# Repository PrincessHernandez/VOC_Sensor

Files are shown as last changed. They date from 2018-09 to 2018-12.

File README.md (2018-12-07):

# Build Instructions for Raspberry Pi VOC Sensor

## Table of Contents
1. [Introduction](#introduction)
2. [Material Requirements](#material-requirements)
3. [Raspberry Pi Configuration](#raspberry-pi-configuration)
4. [Mechanical Assembly and Soldering](#mechanical-assembly-and-soldering)
5. [I2C Detection](#i2c-detection)
6. [Power Up](#power-up)
7. [Explore with your Sensor](#explore-with-your-sensor)

### Introduction
Volatile Organic Compounds (VOC) can be found in everyday products such as cleaning supplies, paint, cosmetic products, fuel, and many more. They have the potential to contaminate our health, so monitoring air quality is very crucial for our everyday means. The CCS811 Air Quality Sensor can sense VOC and CO2, two parameters that are important for monitoring air quality. The following instructions are provided to assist you in developing a VOC sensor that can measure TVOC and eCO2 levels in the air.
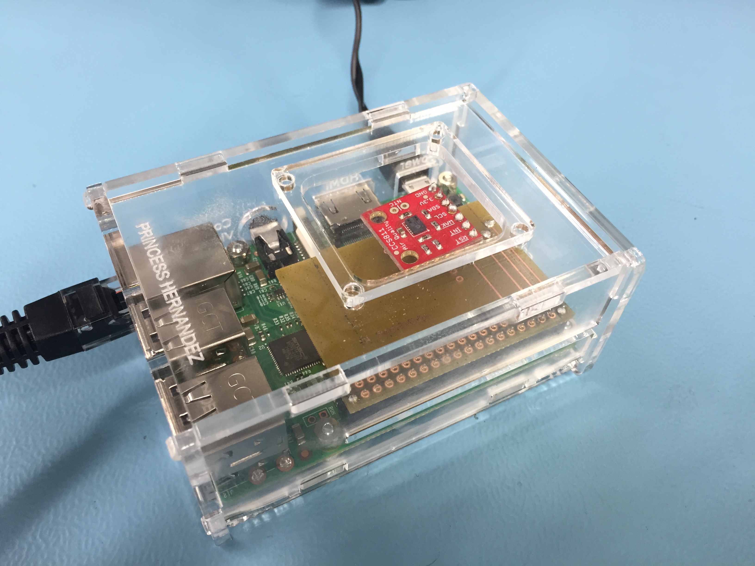
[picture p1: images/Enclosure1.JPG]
<br/></p>

> I recommend that before attempting this build that you have accomplished watching videos on [soldering](https://www.youtube.com/watch?v=BLfXXRfRIzY&list=PLQ32vZrF5U2lFOJTtZDytBWBYVLNp4RYz). 

### Material Requirements
The project's total budget will cost you approx. CAD$232.12 excluding tax and shipping. The prices can be converted depending on where you are from. If you would like to see my personal budget click [here](https://github.com/PrincessHernandez/VOC_Sensor/blob/master/documentation/BudgetUpdated.xlsx). Keep in mind that my budget costs lower because I own some of the parts (or had access to in Prototype Lab) from the list.
The following links below are sources of where you can purchase the items:
* [Raspberry Pi 3 Kit](https://www.amazon.ca/CanaKit-Raspberry-Complete-Starter-Kit/dp/B01CCF6V3A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) - CAD$99.99
* [CCS811 Air Quality Sensor](https://www.sparkfun.com/products/14193) - CAD$28.05
* [Break Away Headers - Straight](https://www.sparkfun.com/products/116) - CAD$2.01
* [7 Pin Receptacle Socket](https://www.creatroninc.com/product/7-pin-receptacle-socket/) - CAD$0.45
* [40 Pin GPIO Connector Header](https://www.buyapi.ca/product/40-pin-gpio-connector-header/) - CAD$1.95
* [Custom PCB](https://www.pcbway.com/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) - CAD$88.88 
<br/>Depending on the design of your PCB prices may vary. 
<br/>You can design your own PCB using [Fritzing](http://fritzing.org/download/) for free. 
<br/>Check out my design of the [PCB](https://github.com/PrincessHernandez/VOC_Sensor/blob/master/documentation/Fritzing%20CCS811/VOC-CCS311-Princess.fzz).
* [Safety Glasses](https://www.amazon.ca/3M-Virtua-Glasses-Polycarbonate-Anti-Scratch/dp/B00AEFBLW2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) - CAD$9.27
* (Optional) [Anti-Static Wrist Strap](https://www.amazon.ca/KingWin-ATS-W24-Anti-Static-Wrist-Strap/dp/B0042TLA90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) - CAD$2.50

### Raspberry Pi Configuration
1. Create your Raspberry Pi's [image](https://github.com/six0four/StudentSenseHat/blob/master/cribpisdcard.md) for your project.

2. Then test your LED to [blink](https://github.com/six0four/StudentSenseHat/blob/master/README.md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).

### Mechanical Assembly and Soldering
1. Make sure to break the 7 pins from the Break Away Header. Then start by soldering the sensor to the pins of the header. 
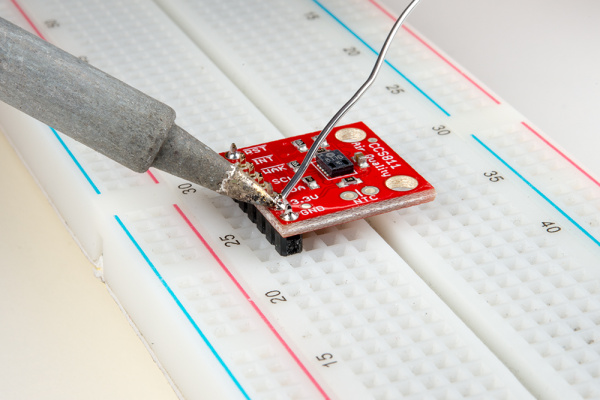
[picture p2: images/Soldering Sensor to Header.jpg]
<br/>

2. You can design your own PCB using [Fritzing software](http://fritzing.org/download/) for free or my version of the [fritzing file](https://github.com/PrincessHernandez/VOC_Sensor/blob/master/documentation/Fritzing%20CCS811/VOC-CCS311-Princess.fzz). You can refer to the image of the schematic and PCB designs below.
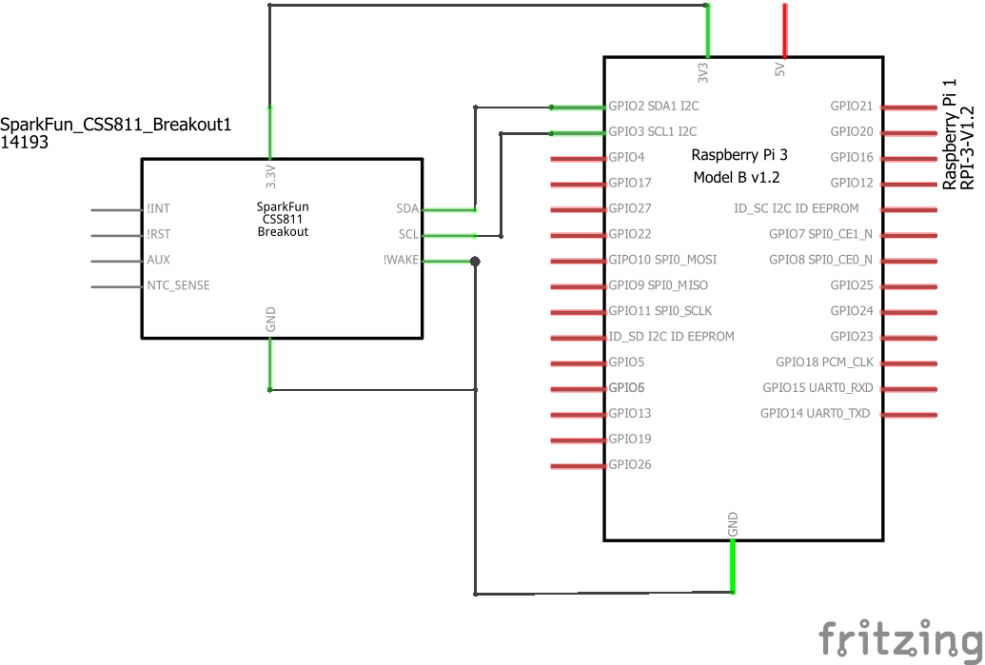
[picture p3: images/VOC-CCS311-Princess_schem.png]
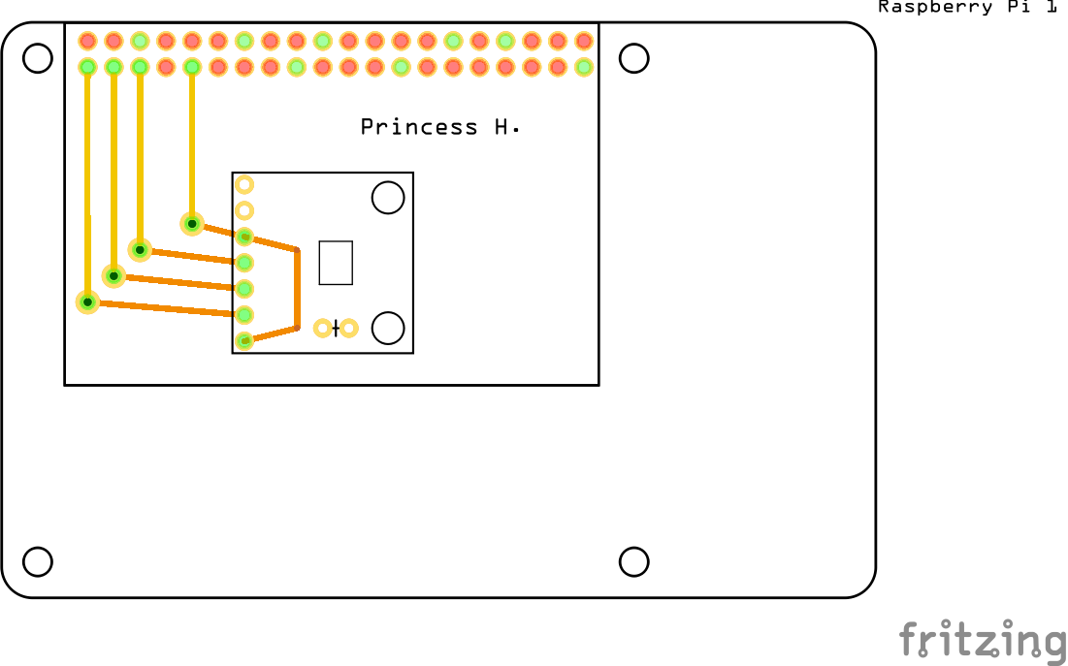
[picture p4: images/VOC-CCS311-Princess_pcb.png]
<br/> 
<br/>Here are the following pins that you should know for this project:
##### Power Pins
* Vin - power pin
	* Since the sensor uses 3.3V, give it the same power as the logic level of you Raspberry Pi.
* GND - common ground for power and logic
##### Logic Pins
* SCL - i2c clock pin
	* Connect to your Raspberry Pi i2c clock line.
* SDA - i2c data pin
	* Connect to your Raspberry Pi i2c data line.
* WAKE\* - wakeup pin for the sensor
	* Please make sure that the WAKE pin is connected to GND. Otherwise, you will not get an address.

3. Once you have obtained your PCB board solder the following:
* Vias\*
* 40-pin socket 
* 7-pin socket
<br/>\*Note: You must thread a single strand of wire through the holes, solder it, and then cut the remaining wires off.

Once you have finished soldering, your board should look like this along with the sensor:
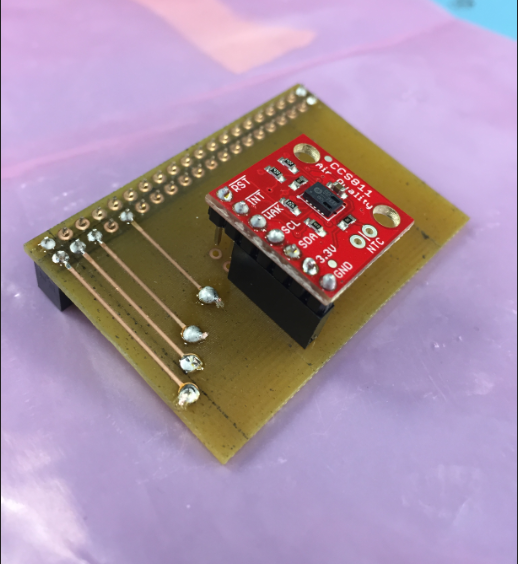
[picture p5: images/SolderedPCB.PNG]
<br/>

### I2C Detection
To check if the board is functioning and detecting the sensor, open terminal and type
```
sudo i2cdetect -y 1
```
This will display an output of the sensor's address - 0x5B. See sample output below:
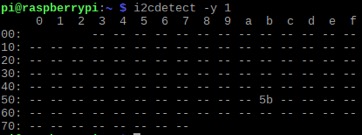
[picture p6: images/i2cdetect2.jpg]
<br/>

### Power Up
To test your sensor download the python code [here](https://github.com/PrincessHernandez/VOC_Sensor/tree/master/documentation/Code). To run the program in the terminal type
```
sudo python ccs811.py
```
`Invalid eCO2 value` detects the CO2 value of greater than what the range should be. You can refer to the sample outputs below. Your output differs depending on your surrounding environment.
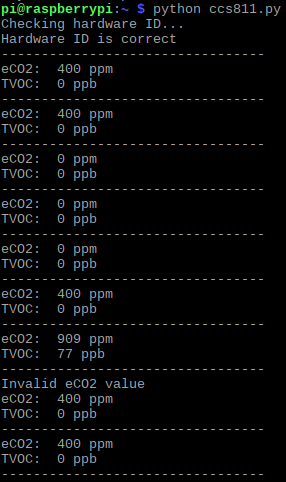
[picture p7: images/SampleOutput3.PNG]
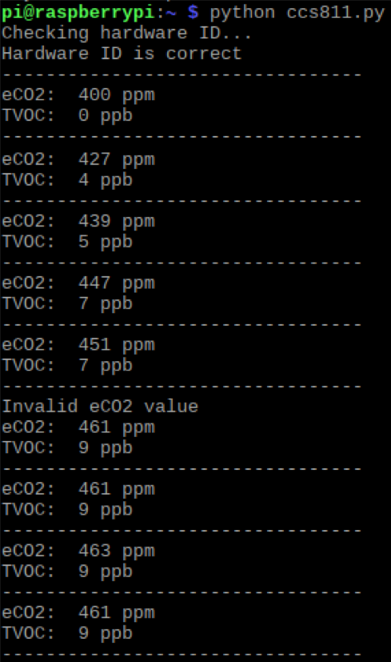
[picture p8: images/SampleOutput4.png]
<br/>  
> **Burn-in Time** - The CCS811 data sheet recommends a burn-in of 48 hours and run-in of 20 minutes. It is important for your sensor to warm up for 20 minutes for a valid output data.

### Explore with your Sensor
You are now ready to conduct experiments with your VOC sensor.

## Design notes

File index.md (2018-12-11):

---
tagline: Website with GitHub Pages
description: Simple website with GitHub Pages
layout: page
title: VOC Sensor Project Blog
---

# CENG317 VOC Sensor Project

### Week 15 December 11, 2018
* The build instructions is due today. I have included all the requirements and instructions for the project. Click [here](https://github.com/PrincessHernandez/VOC_Sensor/blob/master/README.md) for the instructions.

### Week 13 November 27, 2018
* Today is my [presentation](https://github.com/PrincessHernandez/VOC_Sensor/blob/master/documentation/Presentation/VOC%20Sensor.pptx).
* I started a rough copy of my build instructions.

### Week 12 November 20, 2018
* Project enclosure is due today.
* The [design](https://github.com/PrincessHernandez/VOC_Sensor/blob/master/documentation/Project%20Enclosure/Pi2Case.pdf) of the enclosure is inspired by the [template](https://github.com/PrincessHernandez/VOC_Sensor/blob/master/documentation/Project%20Enclosure/Template/Pi2CaseX6.pdf) created for reference purposes. I increased the height by 0.25" and I added a cutout of where the sensor would position at the top of the enclosure. I also added a cover for the cutout when the Pi is not in used.
* The following pictures below is the final project enclosure:

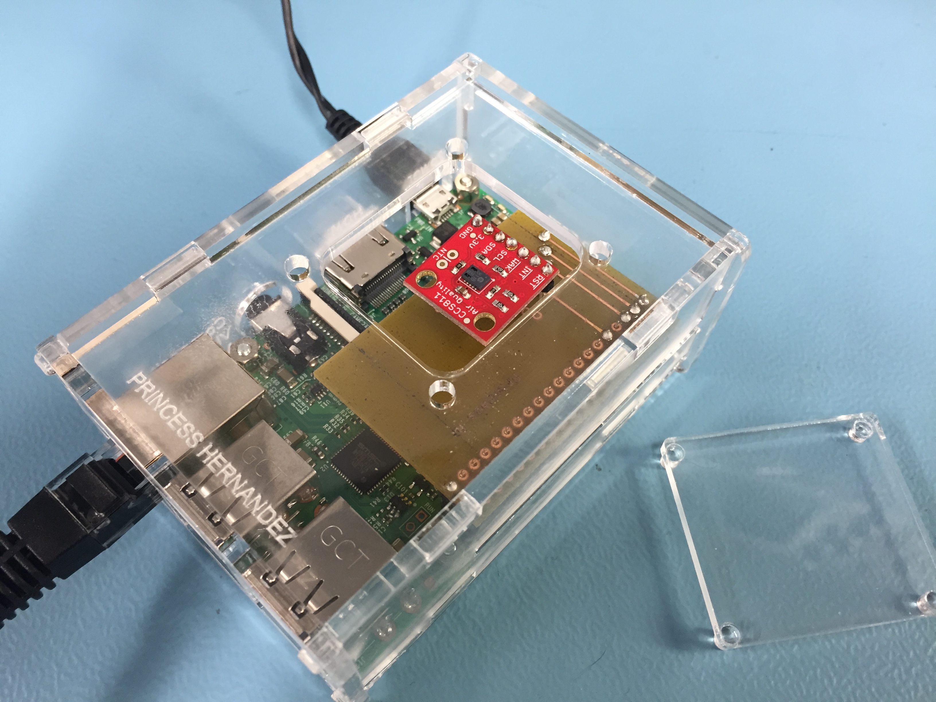
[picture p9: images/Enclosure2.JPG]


### Week 11 November 13, 2018 - Milestone
* PCB Power Up is due today. 
* CCS811 is working as intended. I will be modifying the [code](https://github.com/PrincessHernandez/VOC_Sensor/tree/master/documentation/Code) to get rid of temperatue/humidity compensation because I don't need it in my project. Apart from that, it detects levels of ECO2 and TVOC which are both mentioned in my [proposal](https://github.com/PrincessHernandez/VOC_Sensor/blob/master/documentation/ProposalContentPrincessRev02.xlsx). The following images are samples of output detected from CCS811.

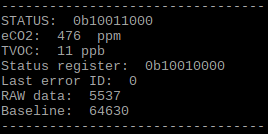
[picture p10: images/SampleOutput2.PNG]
Image of Output1

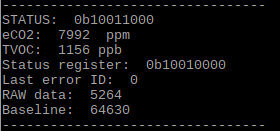
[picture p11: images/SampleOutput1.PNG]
Image of Output2

* I also started designing the case with the help of the [template](https://github.com/PrincessHernandez/VOC_Sensor/blob/master/documentation/Project%20Enclosure/Template/Pi2CaseX6.pdf) provided for us.

#### Update
* The code is now modified (Nov 26).

### Week 10 November 6, 2018
* PCB milestone is due today. I have yet to solder the 7 pin socket.
* I am currently behind my [project schedule](https://github.com/PrincessHernandez/VOC_Sensor/blob/master/documentation/ProjectSchedule.mpp).
* I soldered my PCB on Nov 5. I am still waiting for the 7 pin socket I ordered online. I found out that Canada Post is on strike, so I will wait for my order to arrive by the end of this week. Otherwise I will buy the socket before Friday to finish soldering.
* I got a 5 pin socket from the Prototype Lab and used it as an alternate socket for my sensor since I only need 5 pins from my sensor.

Image of PCB Soldered

### Week 9 October 30, 2018
* I designed my PCB through [Fritzing](https://github.com/PrincessHernandez/VOC_Sensor/blob/master/documentation/Fritzing%20CCS811/VOC-CCS311-Princess.fzz). The fritzing images are in the following:
     
      Breadboard     
    
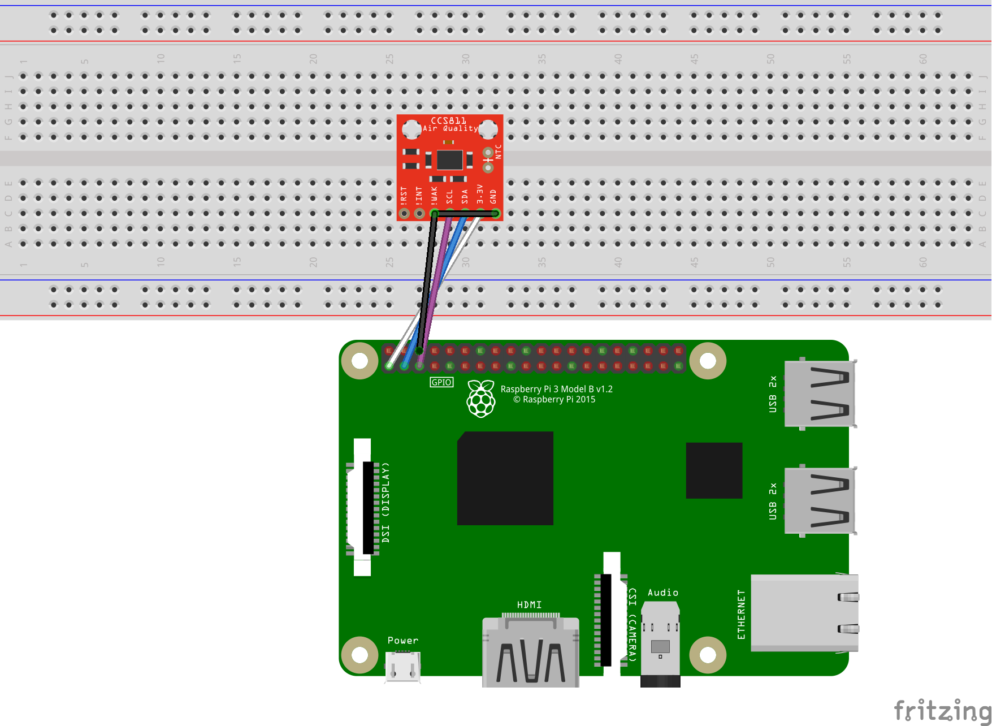
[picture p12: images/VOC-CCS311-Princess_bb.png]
Image of Breadboard

     
      Schematic
    
Image of Schematic
    
      PCB     
    
Image of PCB
* I submitted my [Gerber files](https://github.com/PrincessHernandez/VOC_Sensor/tree/master/documentation/Gerber/VOC%20CCS811) to Prototype Lab.
* I updated my project's [budget](https://github.com/PrincessHernandez/VOC_Sensor/blob/master/documentation/BudgetUpdated.xlsx) to accommodate for the PCB. 
* I sent my Gerber file again on Nov 2. PCB is expected Nov 5. 

### Week 8 October 23, 2018 - Milestone
* I forgot my Raspberry Pi. 
* Demonstrated wiring on breadboard (borrowed Rasp Pi from Parts Crib).

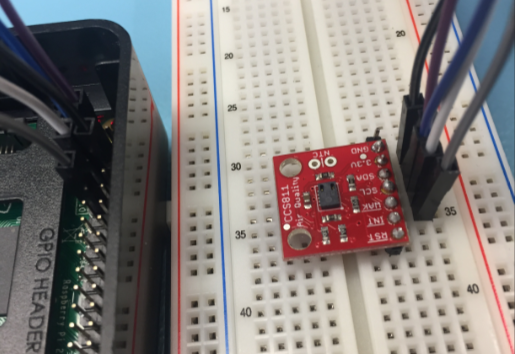
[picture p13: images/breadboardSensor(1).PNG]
Image of Wiring1
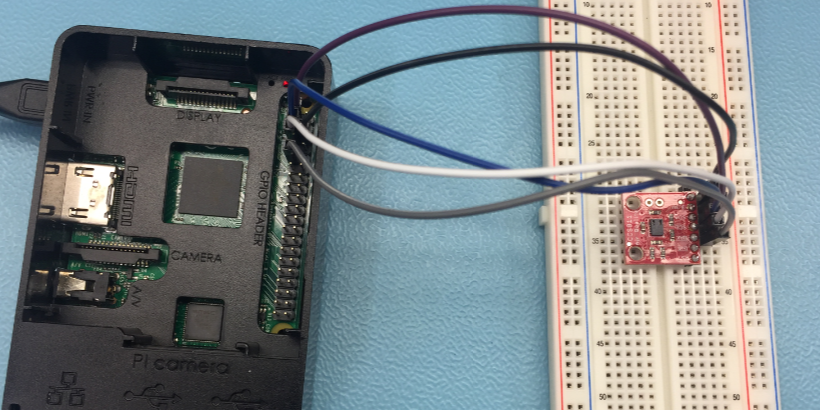
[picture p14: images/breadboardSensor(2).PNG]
Image of Wiring2
 
* Used i2cdetect command to detect CCS811 sensor on the pi. The result is the correct address (0x5B).

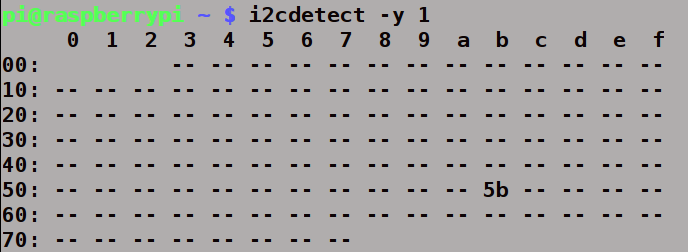
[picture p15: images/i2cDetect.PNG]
Image of Sensor Detected


### Week 7 October 16, 2018
* Pseudo code assignment due.

### Week 6 October 9, 2018 - Study Day
* Soldered my sensor to the header.

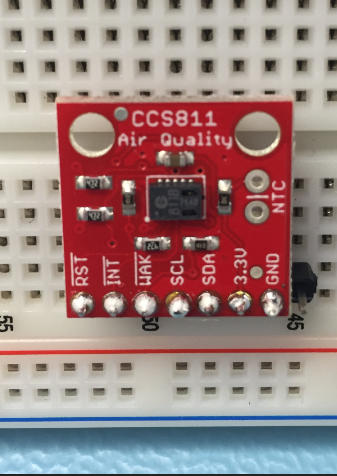
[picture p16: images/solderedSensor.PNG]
Image of Soldered Sensor

* Worked on Pseudo code assignment.

### Week 5 October 2, 2018
* I showed proof of ordered parts.
* Setting up Raspberry Pi.

### Week 4 September 25, 2018
* I submitted my [budget](https://github.com/PrincessHernandez/VOC_Sensor/blob/master/documentation/Budget.xlsx).
* I ordered my parts on September 27.

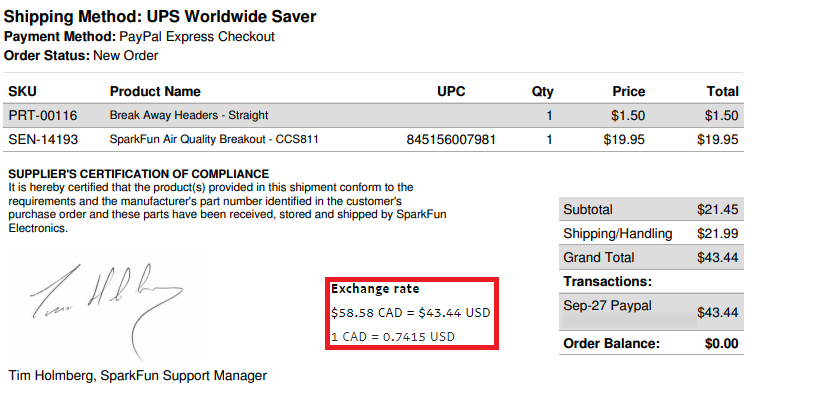
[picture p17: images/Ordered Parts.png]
Image of Parts Receipt

* I paid for import charges and received my parts on September 28.

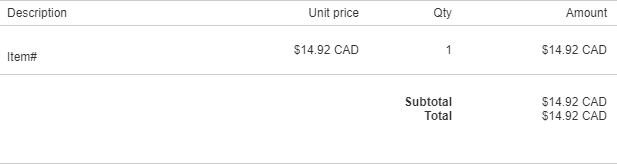
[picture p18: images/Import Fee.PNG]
Image of Import Fee Receipt


### Week 3 September 18, 2018
* I submitted my [project schedule](https://github.com/PrincessHernandez/VOC_Sensor/blob/master/documentation/ProjectSchedule.mpp).
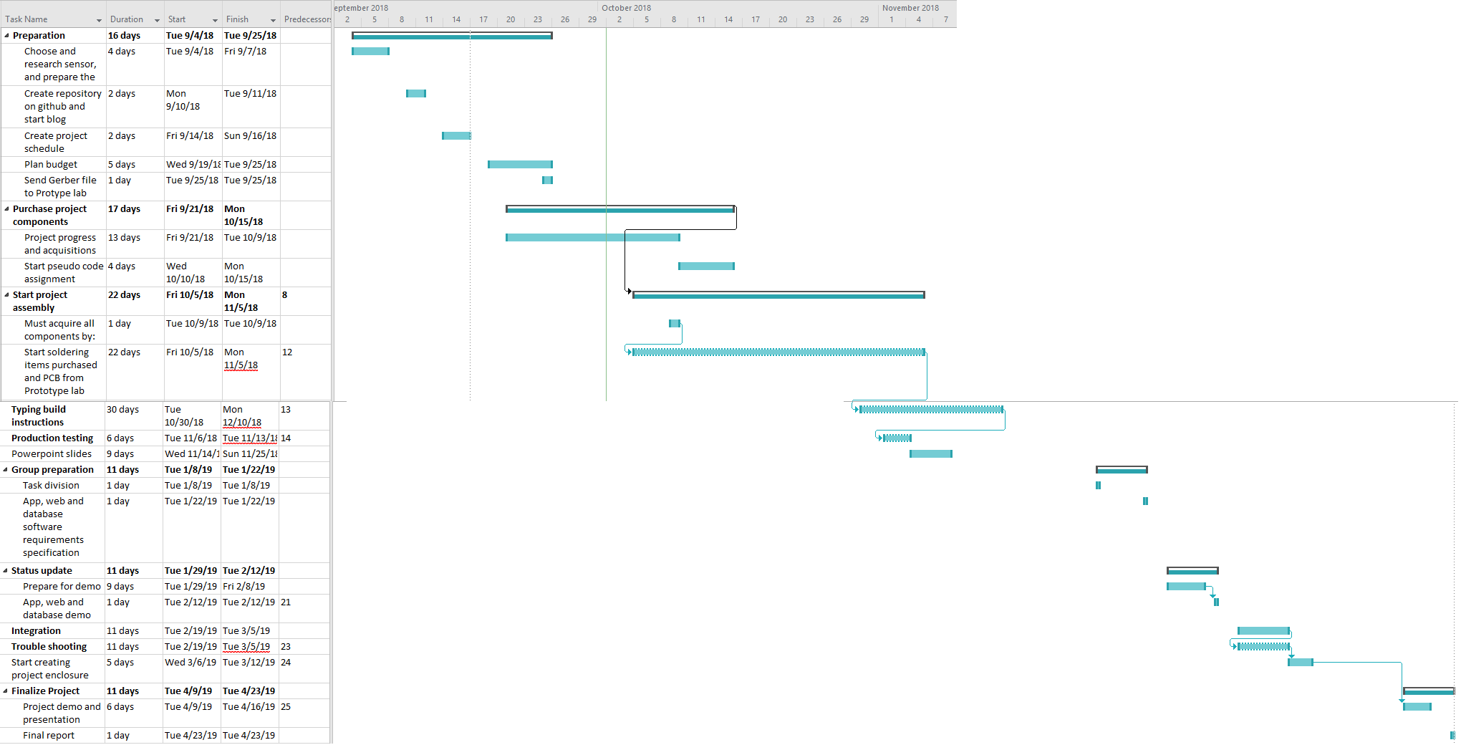
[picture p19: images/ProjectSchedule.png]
Image of Project Schedule


### Week 2 September 11, 2018
* I submitted my [proposal](https://github.com/PrincessHernandez/VOC_Sensor/blob/master/documentation/ProposalContentPrincessRev02.xlsx).

### Week 1 September 4, 2018
* I created my [repository](https://github.com/PrincessHernandez/VOC_Sensor) and choose the sensor that I will be building with for my IoT Hardware project.
* The sensor I chose is a VOC sensor.

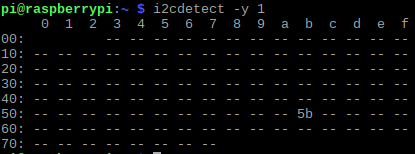
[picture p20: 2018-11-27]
images/DetectAddress.PNG

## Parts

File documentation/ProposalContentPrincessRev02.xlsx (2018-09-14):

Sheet: DataEntry
Submission Date | 2018-09-11
Project Name | Air Quality Monitor
Student Name | Princess Hernandez
Project repository | https://princesshernandez.github.io/VOC_Sensor/
SensorEffector choice | CCS811/BME280 VOC sensor (0x5B)
The database will store | toxic and combustible gas level data retrieved from the device
The mobile device functionality will include | a series readings of Total Volatile Organic Compounds (TVOC) and equivalent carbon dioxide (eCO2), as well as the date the data is retrieved.
I will be collaborating with the following company/department | Arduino or Raspberry Pi, Prototype Lab, Aeroqual, SYFT Technologies, GasSensing
My group in the winter semester will include | Kenneth Chen
50 word problem statement | Volatile Organic Compounds (VOC) are carbon based chemicals that can be natural or man-made in the environment. Some are significantly hazardous to human health, and even the environment, when an extensive amount is present in the air due to odourless or colourless gas. When exposed to VOC, it can cause damage to major organs in the body such as lungs, stomach, nerves and brain.
100 words of background | The VOC sensor can detect hazardous compounds by photoionization. It uses ultraviolet light to ionize compounds in the air into positive and negative ions to determine any toxins present. The sensor can measure equivalent calculated carbon dioxide (eCO2) within the range of 400 to 8192 parts per million (ppm) and Total Volatile Organic Compound (TVOC) concentration within the range of 0 to 1187 parts per billion (ppb). Therefore, it is able to detect different types of toxic and combustible gases in the air accurately.
Current product APA citation | Miller, Dean. (2017, August 2). Adafruit CCS811 Air Quality Sensor Raspberry Pi Wiring & Test. Adafruit. Retrieved from: https://learn.adafruit.com/adafruit-ccs811-air-quality-sensor/raspberry-pi-wiring-test
Existing research IEEE paper APA citation | Fang, L., Ding, Z. & Li, Jinhai. (2010, April 19). Temperature and flow rate compensation for air auto-monitoring system based on multi-sensor data fusion. Retrieved from: https://ieeexplore.ieee.org/document/5451735/
Brief description of planned purchases | The Raspberry Pi will be used as a main component of the project. CCS811/BME280 VOC is a sensor that measures indoor air quality. QWIIC Shield for Raspberry Pi.
Solution description | VOCs can be found in everyday products such as cleaning supplies, paint, cosmetic products, fuel and many more. Both short and long term exposure to a high amount concentration of VOC can lead to human health deterioration. For example, in many workplaces, like the oil and gas industries, there may be a limited amount of ventilation and workers being exposed to such air can cause the company or industry a large amount of money for improper workplace environment. So, every level (low and high) of VOC concentration must be monitored.

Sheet: DataBase
Submission Date | Project Name | Student Name | Project repository | SensorEffector choice | The database will store | The mobile device functionality will include | I will be collaborating with the following company/department | My group in the winter semester will include | 50 word problem statement | 100 words of background | Current product APA citation | Existing research IEEE paper APA citation | Brief description of planned purchases | Solution description
43354 | Air Quality Monitor | Princess Hernandez | https://princesshernandez.github.io/VOC_Sensor/ | CCS811/BME280 VOC sensor (0x5B) | toxic and combustible gas level data retrieved from the device | a series readings of Total Volatile Organic Compounds (TVOC) and equivalent carbon dioxide (eCO2), as well as the date the data is retrieved. | Arduino or Raspberry Pi, Prototype Lab, Aeroqual, SYFT Technologies, GasSensing | Kenneth Chen | Volatile Organic Compounds (VOC) are carbon based chemicals that can be natural or man-made in the environment. Some are significantly hazardous to human health, and even the environment, when an extensive amount is present in the air due to odourless or colourless gas. When exposed to VOC, it can cause damage to major organs in the body such as lungs, stomach, nerves and brain. | The VOC sensor can detect hazardous compounds by photoionization. It uses ultraviolet light to ionize compounds in the air into positive and negative ions to determine any toxins present. The sensor can measure equivalent calculated carbon dioxide (eCO2) within the range of 400 to 8192 parts per million (ppm) and Total Volatile Organic Compound (TVOC) concentration within the range of 0 to 1187 parts per billion (ppb). Therefore, it is able to detect different types of toxic and combustible gases in the air accurately. | Miller, Dean. (2017, August 2). Adafruit CCS811 Air Quality Sensor Raspberry Pi Wiring & Test. Adafruit. Retrieved from: https://learn.adafruit.com/adafruit-ccs811-air-quality-sensor/raspberry-pi-wiring-test | Fang, L., Ding, Z. & Li, Jinhai. (2010, April 19). Temperature and flow rate compensation for air auto-monitoring system based on multi-sensor data fusion. Retrieved from: https://ieeexplore.ieee.org/document/5451735/ | The Raspberry Pi will be used as a main component of the project. CCS811/BME280 VOC is a sensor that measures indoor air quality. QWIIC Shield for Raspberry Pi. | VOCs can be found in everyday products such as cleaning supplies, paint, cosmetic products, fuel and many more. Both short and long term exposure to a high amount concentration of VOC can lead to human health deterioration. For example, in many workplaces, like the oil and gas industries, there may be a limited amount of ventilation and workers being exposed to such air can cause the company or industry a large amount of money for improper workplace environment. So, every level (low and high) of VOC concentration must be monitored.

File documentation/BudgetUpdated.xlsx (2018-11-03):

Princess Hernandez N01099524
Air Quality Monitor Parts
Description | Source | Part # | $USD Price | $CAD Price | $USD Total | $CAD Total | Link
SparkFun Air Quality Breakout - CCS811 | Sparkfun | SEN-14193 | $19.95 |  |  |  | https://www.sparkfun.com/products/14193?_ga=2.97662492.2095878335.1537831851-1448490607.1536633859
Break Away Headers - Straight | Sparkfun | PRT-00116 | $1.50 |  |  |  | https://www.sparkfun.com/products/116?_ga=2.161208638.2095878335.1537831851-1448490607.1536633859
Import Fee |  |  |  | $14.92
Shipping and Handling |  |  | $21.99
 |  |  |  |  |  | $73.50
7 Pin Receptacle Socket | Creatron Inc. | CONHD-000007 |  | $0.45 |  |  | https://www.buyapi.ca/product/40-pin-gpio-connector-header/
Tax and Customs |  |  |  | $0.02
Shipping and Hanlding |  |  |  | N/A
 |  |  |  |  |  | $0.47
Raspberry Pi 3 Starter Kit | Amazon | N/A | N/A | N/A | N/A | N/A
Humber Parts kit | Bookstore | N/A | N/A | N/A | N/A | N/A
PCB | Prototype Lab | N/A | N/A | N/A | N/A | N/A
Grand Total (using CAD$1=USD$0.77) |  |  |  |  | $88.13

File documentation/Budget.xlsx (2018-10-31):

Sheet: Sheet1
Princess Hernandez N01099524
Air Quality Monitor Parts
Description | Source | Part # | $USD Price | $CAD Price | $USD Total | $CAD Total | Link
SparkFun Air Quality Breakout - CCS811 | Sparkfun | SEN-14193 | $19.95 |  |  |  | https://www.sparkfun.com/products/14193?_ga=2.97662492.2095878335.1537831851-1448490607.1536633859
Break Away Headers - Straight | Sparkfun | PRT-00116 | $1.50 |  |  |  | https://www.sparkfun.com/products/116?_ga=2.161208638.2095878335.1537831851-1448490607.1536633859
Tax and Customs |  |  | $2.79
Shipping and Handling |  |  | $24.72
 |  |  |  |  | $48.96
Raspberry Pi 3 Starter Kit | Amazon | N/A | N/A | N/A | N/A | N/A
Humber Parts kit | Bookstore | N/A | N/A | N/A | N/A | N/A
PCB | Prototype Lab | N/A | N/A | N/A | N/A | N/A
Grand Total (using CAD$1=USD$0.77) |  |  |  |  | $63.43

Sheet: Sheet2
Princess Hernandez N01099524
Air Quality Monitor Parts
Description | Source | Part # | $USD Price | $CAD Price | $USD Total | $CAD Total | Link
SparkFun Environmental Combo Breakout - CCS811/BME280 (Qwiic) | Sparkfun | SEN-14348 | $34.95 |  |  |  | https://www.sparkfun.com/products/14193?_ga=2.97662492.2095878335.1537831851-1448490607.1536633859
SparkFun Qwiic HAT for Raspberry Pi | Sparkfun | DEV-14459 | $4.95 |  |  |  | https://www.sparkfun.com/products/14459?_ga=2.64157484.2095878335.1537831851-1448490607.1536633859
Qwiic Cable - 500mm | Sparkfun | PRT-14429 | $1.95 |  |  |  | https://www.sparkfun.com/products/14429?_ga=2.93074078.2095878335.1537831851-1448490607.1536633859
Tax and Customs |  |  | ??
Shipping and Handling |  |  | ??
 |  |  |  |  | ????
Raspberry Pi 3 Starter Kit | Amazon | N/A | N/A | N/A | N/A | N/A
Humber Parts kit | Bookstore | N/A | N/A | N/A | N/A | N/A
PCB | Prototype Lab | N/A | N/A | N/A | N/A | N/A
Grand Total (using CAD$1=USD$0.77) |  |  |  |  | ????

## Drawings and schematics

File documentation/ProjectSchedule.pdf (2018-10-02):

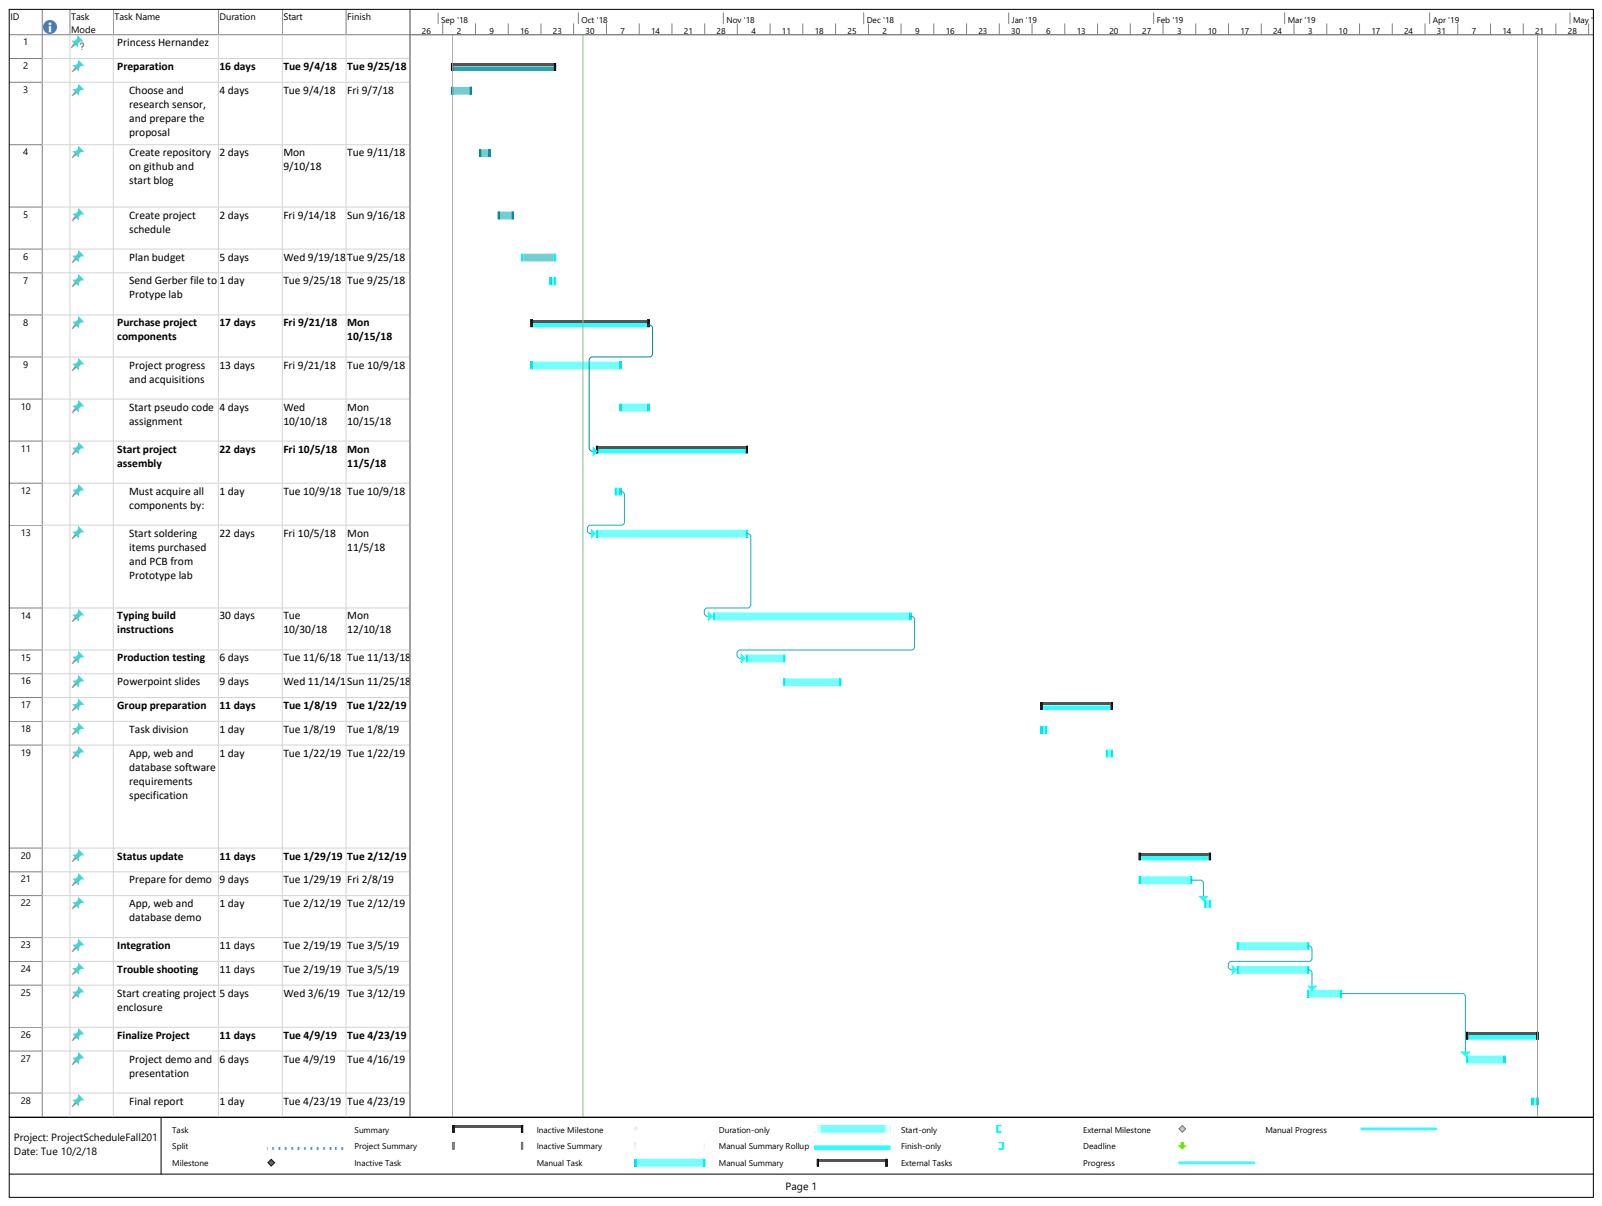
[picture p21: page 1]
Task; Mode; Task Name; Duration; Start; Finish; Princess Hernandez; Preparation; 16 days; Tue 9/4/18; Tue 9/25/18; Choose and; 4 days; Fri 9/7/18; Create repository; 2 days; Mon; Tue 9/11/18; Create project; schedule; Fri 9/14/18; Sun 9/16/18; Plan budget; 5 days; Wed 9/19/18Tue 9/25/18; Send Gerber file to; Protype lab; 1 day; Purchase project; components; 17 days; Fri 9/21/18; Project progress; and acquisitions; 13 days; Tue 10/9/18; Start pseudo code; assignment; Wed; Mon 10/15/18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

research sensor,
and prepare the
proposal

on github and
start blog

items purchased
and PCB from
Prototype lab

Duration-only
Manual Summary Rollup
Manual Summary

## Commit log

2018-09-14 proposal added
    [ProposalContentPrincessRev02.xlsx, ProposalContentStudentNameRev02.xlsx]
2018-12-06 i2c detect 2
